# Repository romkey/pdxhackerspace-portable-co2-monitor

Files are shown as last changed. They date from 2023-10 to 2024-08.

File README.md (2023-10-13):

# Build Your Own Portable CO2 Monitor

Build Your Own Portable CO2 Monitor is a [PDX Hackerspace] project.

## Design Goals

- minimize cost
- true CO2 measurement
- choice of displays
- optional Home Assistant integration
- optional battery operation
- version that people who are inexperienced with soldering can build
- more integrated version for people who can assemble surface mount hardware
- open source software and hardware

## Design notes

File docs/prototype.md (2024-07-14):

# Prototype

I built a quick prototype using STEMMA QT/Qwiic connectors. I didn't have any BME280s handy so I used the BME680, which is basically the same thing with a VOC sensor added to it.

STEMMA QT and Qwiic are Adafruit and Sparkfun's branding for identical connectors that allow you to quickly connect 3.3V I2C boards. I2C is great for sensors and very small monochrome displays but it's not fast enough for larger or more colorful displays that need much more data transferred. I2C devices rarely support speeds faster than 400Kbps. Displays that need more speed generally use SPI or parallel or proprietary interfaces.

## Parts

[Adafruit ESP32-S3 QT PY](https://learn.adafruit.com/adafruit-qt-py-esp32-s3/overview)
[SCD40](https://learn.adafruit.com/adafruit-scd-40-and-scd-41)
[BME680](https://learn.adafruit.com/adafruit-bme680-humidity-temperature-barometic-pressure-voc-gas)
[PMSA003I](https://learn.adafruit.com/pmsa003i)
[OLED display]()

## Software

ESPHome components:
[SCD40](https://esphome.io/components/sensor/scd4x)
[BME680](https://esphome.io/components/sensor/bme680)
[PMSA003I](https://esphome.io/components/sensor/pmsa003i)
[SSD1306 OLED](https://esphome.io/components/display/ssd1306)
[Display pages](https://esphome.io/components/display/#display-pages)
[Graphs](https://esphome.io/components/display/#graph-component)

## TODO

The first prototype serves as a proof-of-concept. There are still several areas that need to be verified:

1. running off a battery
2. wireless charging
3. SPI TFT display
4. e-ink display
5. PMS5003 via serial

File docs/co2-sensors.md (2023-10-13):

# CO2 Sensor List

|Device | Interface | Unit cost | Range | Avg Current | Sample Current | Voltage | datasheet
|---|---|---|-----|---|---|---|---
|SCD30| I2C,UART,  PWM | $62 | 400 - 10,000ppm| | | | [datasheet](https://mm.digikey.com/Volume0/opasdata/d220001/medias/docus/743/CD_DS_SCD30_Datasheet_D1.pdf)
|SCD40 | I2C | $30 | 400 - 2000ppm | | | | [datasheet](https://cdn.sparkfun.com/assets/d/4/9/a/d/Sensirion_CO2_Sensors_SCD4x_Datasheet.pdf) |
|SCD41 | I2C | $37 | 400 - 5000ppm | | | | [datasheet](https://cdn.sparkfun.com/assets/d/4/9/a/d/Sensirion_CO2_Sensors_SCD4x_Datasheet.pdf) |
|Senseair S8| UART, I2C | $47 | 400 - 2000ppm | 30mA | | 4.5-5.25V| [datasheet](https://rmtplusstoragesenseair.blob.core.windows.net/docs/publicerat/PSP107.pdf)
|Senseair Sunrise | UART, I2C | $55 | 400 - 5000ppm | 34 µA | 90mA | 3.05-5.5 V | [datasheet](https://rmtplusstoragesenseair.blob.core.windows.net/docs/Dev/publicerat/PSH12460.pdf)
|MH-Z14A | UART | 
|MH-Z19B | UART |
|MQ135| analog | $6 |10～1000ppm | 40mA | 40mA | 5V| [datasheet](https://www.olimex.com/Products/Components/Sensors/Gas/SNS-MQ135/resources/SNS-MQ135.pdf)

* CCS811 and ENS160 are I2C "eCO2" sensors which estimate CO2, not a true CO2 sensors

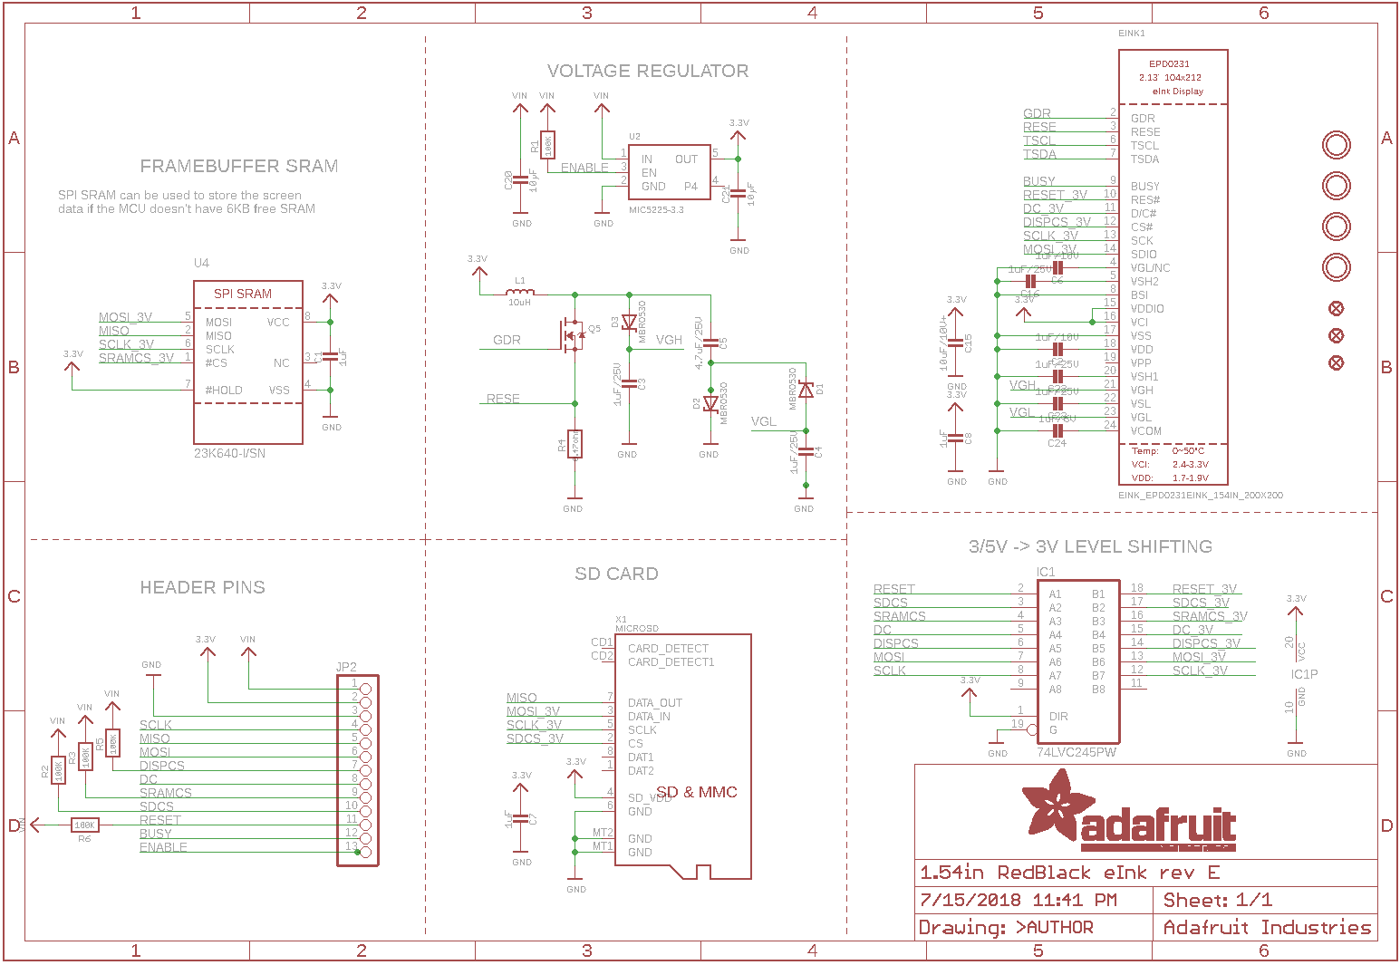
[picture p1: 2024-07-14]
datasheets/adafruit_products_schem.png

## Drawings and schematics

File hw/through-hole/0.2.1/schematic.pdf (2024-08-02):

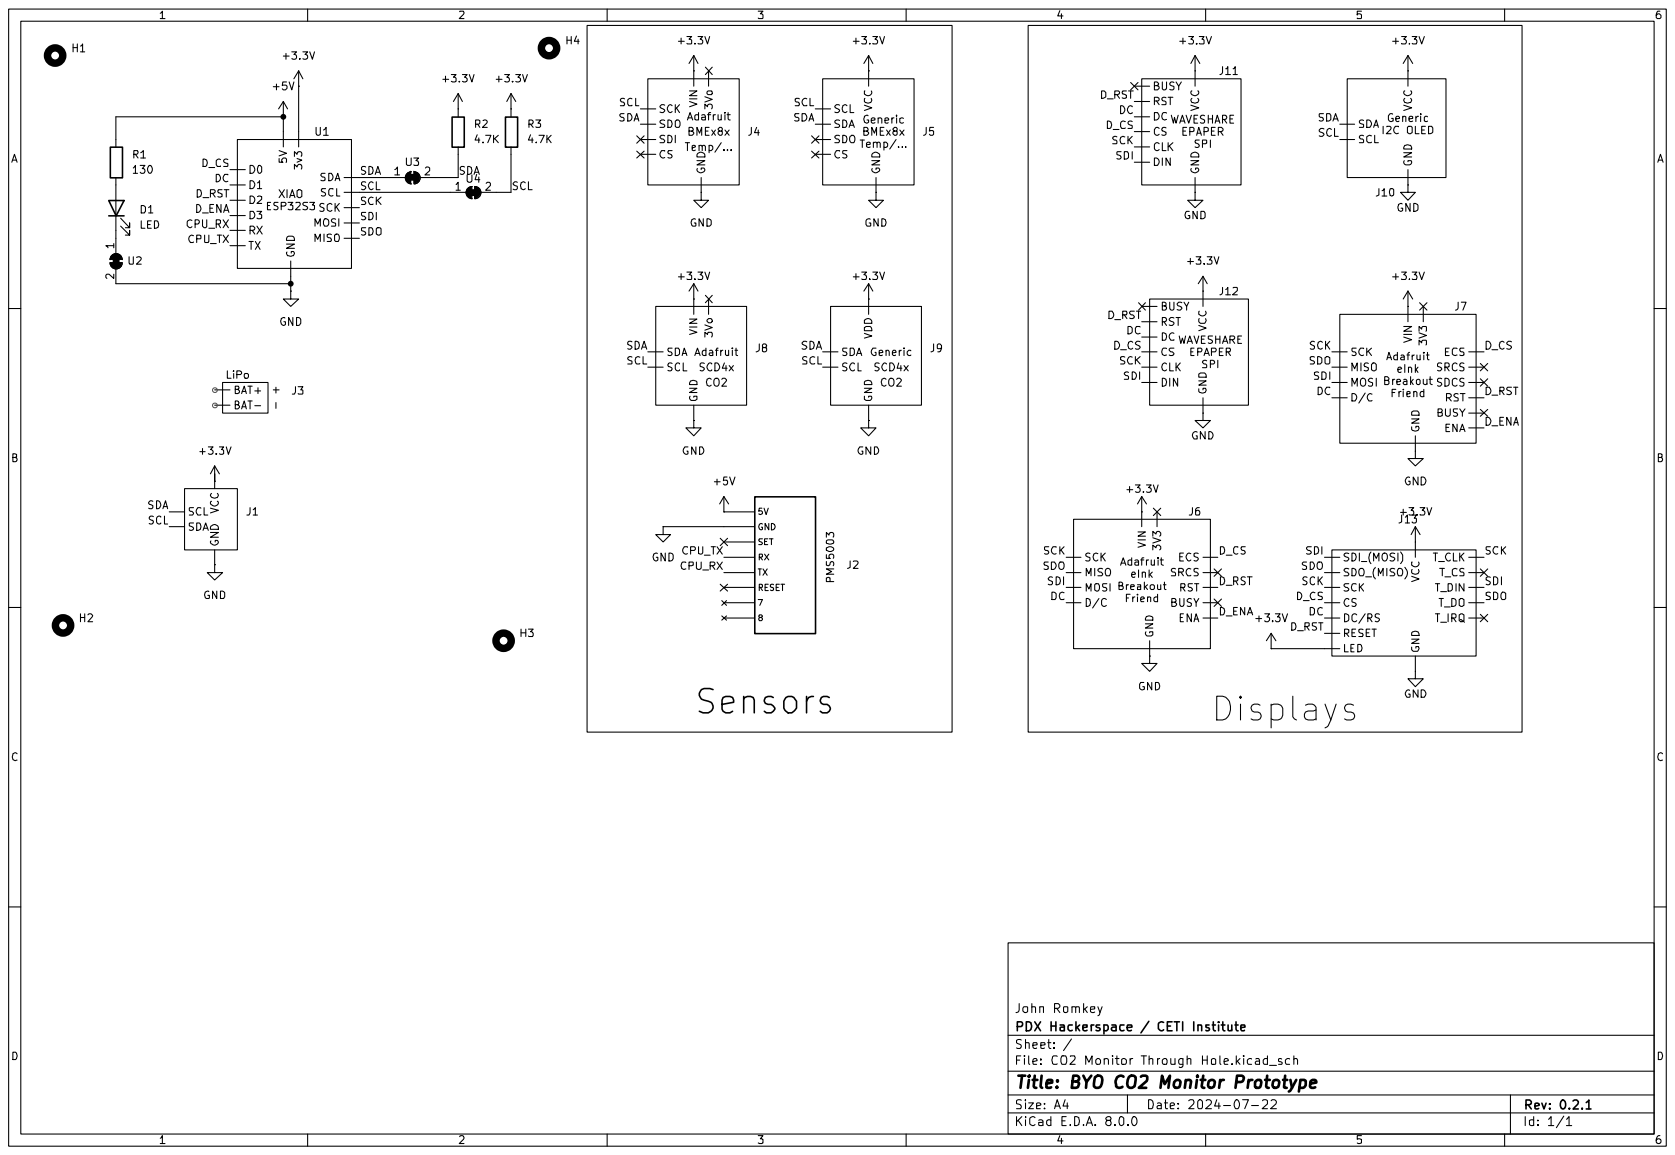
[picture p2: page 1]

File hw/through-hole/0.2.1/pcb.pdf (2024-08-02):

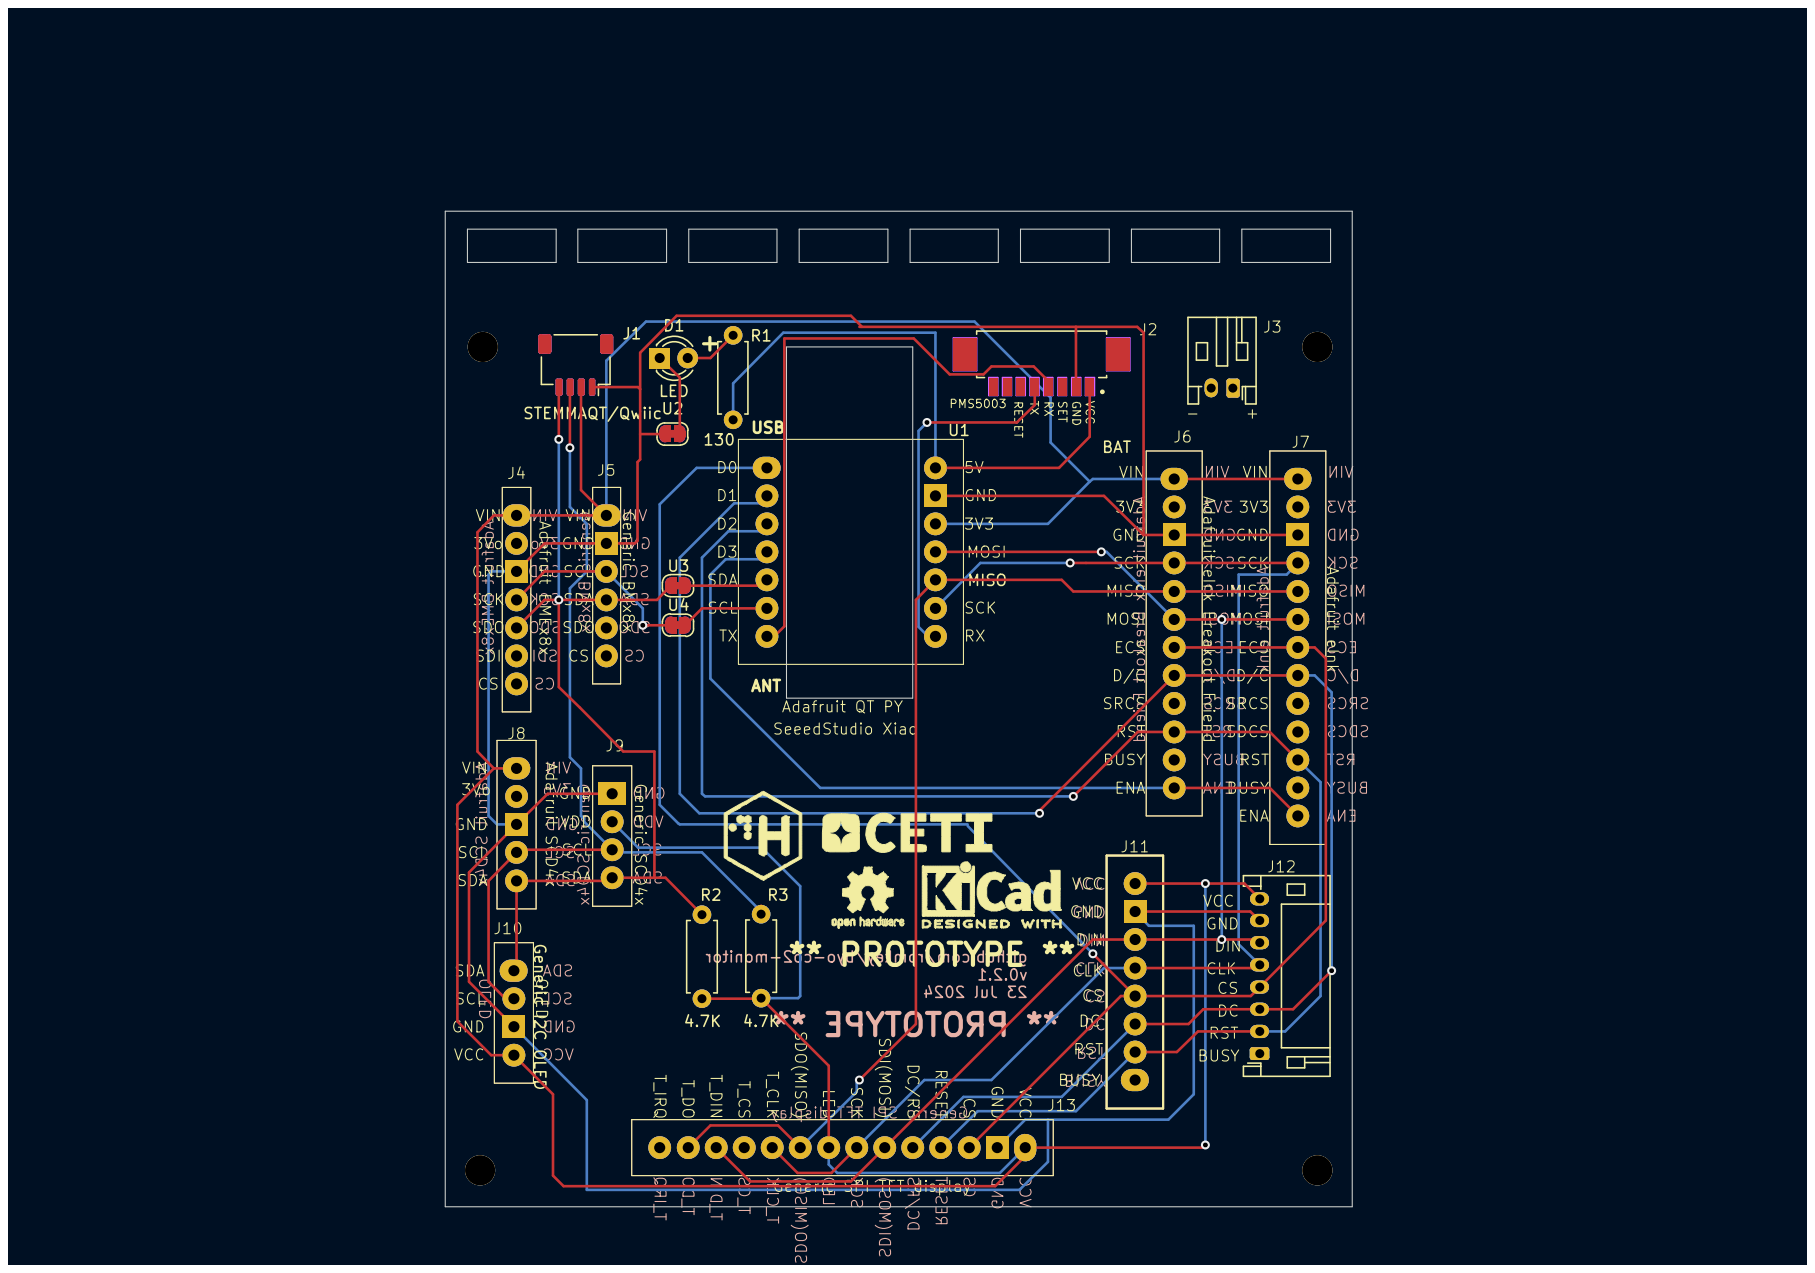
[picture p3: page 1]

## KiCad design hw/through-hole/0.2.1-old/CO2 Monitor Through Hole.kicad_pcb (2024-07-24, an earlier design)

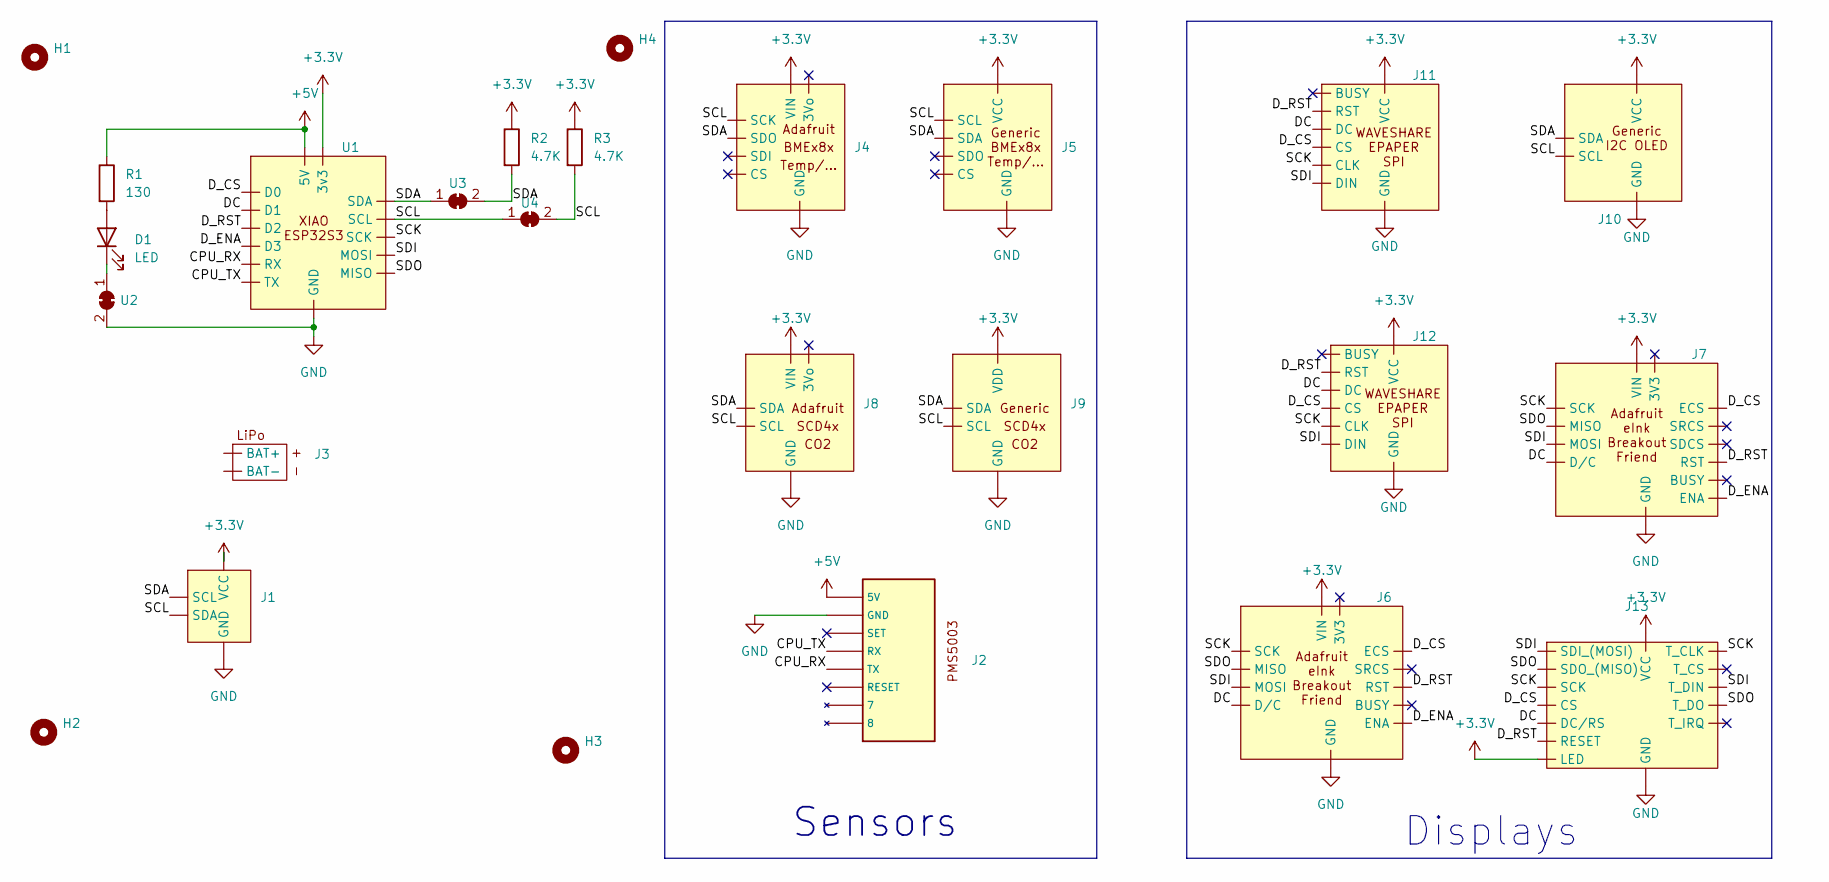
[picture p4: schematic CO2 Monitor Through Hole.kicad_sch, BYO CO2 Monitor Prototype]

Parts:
D1: LED; LED_D3.0mm
H1, H2, H3, H4: MountingHole; MountingHole_2.7mm_M2.5
J1: JST_SH_SM04B-SRSS-TB_1x04-1MP_P1.00mm_Horizontal
J2: PMS5003 Connector
J3: LiPo Connector
J4: Adafruit BMx8x Breakout
J5: Generic BMx8x Breakout
J6: Adafruit eInk Breakout Friend
J7: Adafruit eInk Breakout (GENERIC)
J8: Adafruit SCD4x Breakout
J9: Generic SCD4x Breakout
J10: Generic I2C OLED
J11: Wavshare ePaper SPI
J12: Waveshare ePaper SPI JST
J13: SPI_TFT_TOUCH
R1: 130; R_Axial_DIN0207_L6.3mm_D2.5mm_P7.62mm_Horizontal
R2, R3: 4.7K; R_Axial_DIN0207_L6.3mm_D2.5mm_P7.62mm_Horizontal
U1: Xiao ESP32S3
U2, U3, U4: SolderJumper-2_P1.3mm_Bridged_RoundedPad1.0x1.5mm

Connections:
+3.3V: J1.2 (VCC), J4.1 (VIN), J5.1 (VCC), J6.1 (VIN), J7.1 (VIN), J8.1 (VIN), J9.2 (VDD), J10.4 (VCC), J11.8 (VCC), J12.8 (VCC), J13.1 (VCC), J13.8 (LED), R2.1, R3.1, U1.12 (3v3)
+5V: J2.1 (5V), R1.1, U1.14 (5V)
/CPU_RX: J2.5 (TX), U1.8 (RX)
/CPU_TX: J2.4 (RX), U1.7 (TX)
/DC: J6.8 (D/C), J7.8 (D/C), J11.3 (DC), J12.3 (DC), J13.5 (DC/RS), U1.2 (D1)
/D_CS: J6.7 (ECS), J7.7 (ECS), J11.4 (CS), J12.4 (CS), J13.3 (CS), U1.1 (D0)
/D_ENA: J6.12 (ENA), J7.13 (ENA), U1.4 (D3)
/D_RST: J6.10 (RST), J7.11 (RST), J11.2 (RST), J12.2 (RST), J13.4 (RESET), U1.3 (D2)
/SCK: J6.4 (SCK), J7.4 (SCK), J11.5 (CLK), J12.5 (CLK), J13.7 (SCK), J13.10 (T_CLK), U1.9 (SCK)
/SCL: J1.3 (SDA), J4.4 (SCK), J5.3 (SCL), J8.4 (SCL), J9.3 (SCL), J10.2 (SCL), R3.2, U1.6 (SCL), U4.1 (A), U4.2 (B)
/SDA: J1.4 (SCL), J4.5 (SDO), J5.4 (SDA), J8.5 (SDA), J9.4 (SDA), J10.1 (SDA), R2.2, U1.5 (SDA), U3.1 (A), U3.2 (B)
/SDI: J6.6 (MOSI), J7.6 (MOSI), J11.6 (DIN), J12.6 (DIN), J13.6 (SDI_(MOSI)), J13.12 (T_DIN), U1.11 (MOSI)
/SDO: J6.5 (MISO), J7.5 (MISO), J13.9 (SDO_(MISO)), J13.13 (T_DO), U1.10 (MISO)
GND: J1.1 (GND), J2.2 (GND), J4.3 (GND), J5.2 (GND), J6.3 (GND), J7.3 (GND), J8.3 (GND), J9.1 (GND), J10.3 (GND), J11.7 (GND), J12.7 (GND), J13.2 (GND), U1.13 (GND), U2.2 (B)
unnamed: D1.2 (A), R1.2
unnamed: D1.1 (K), U2.1 (A)

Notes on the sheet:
Sensors
Displays

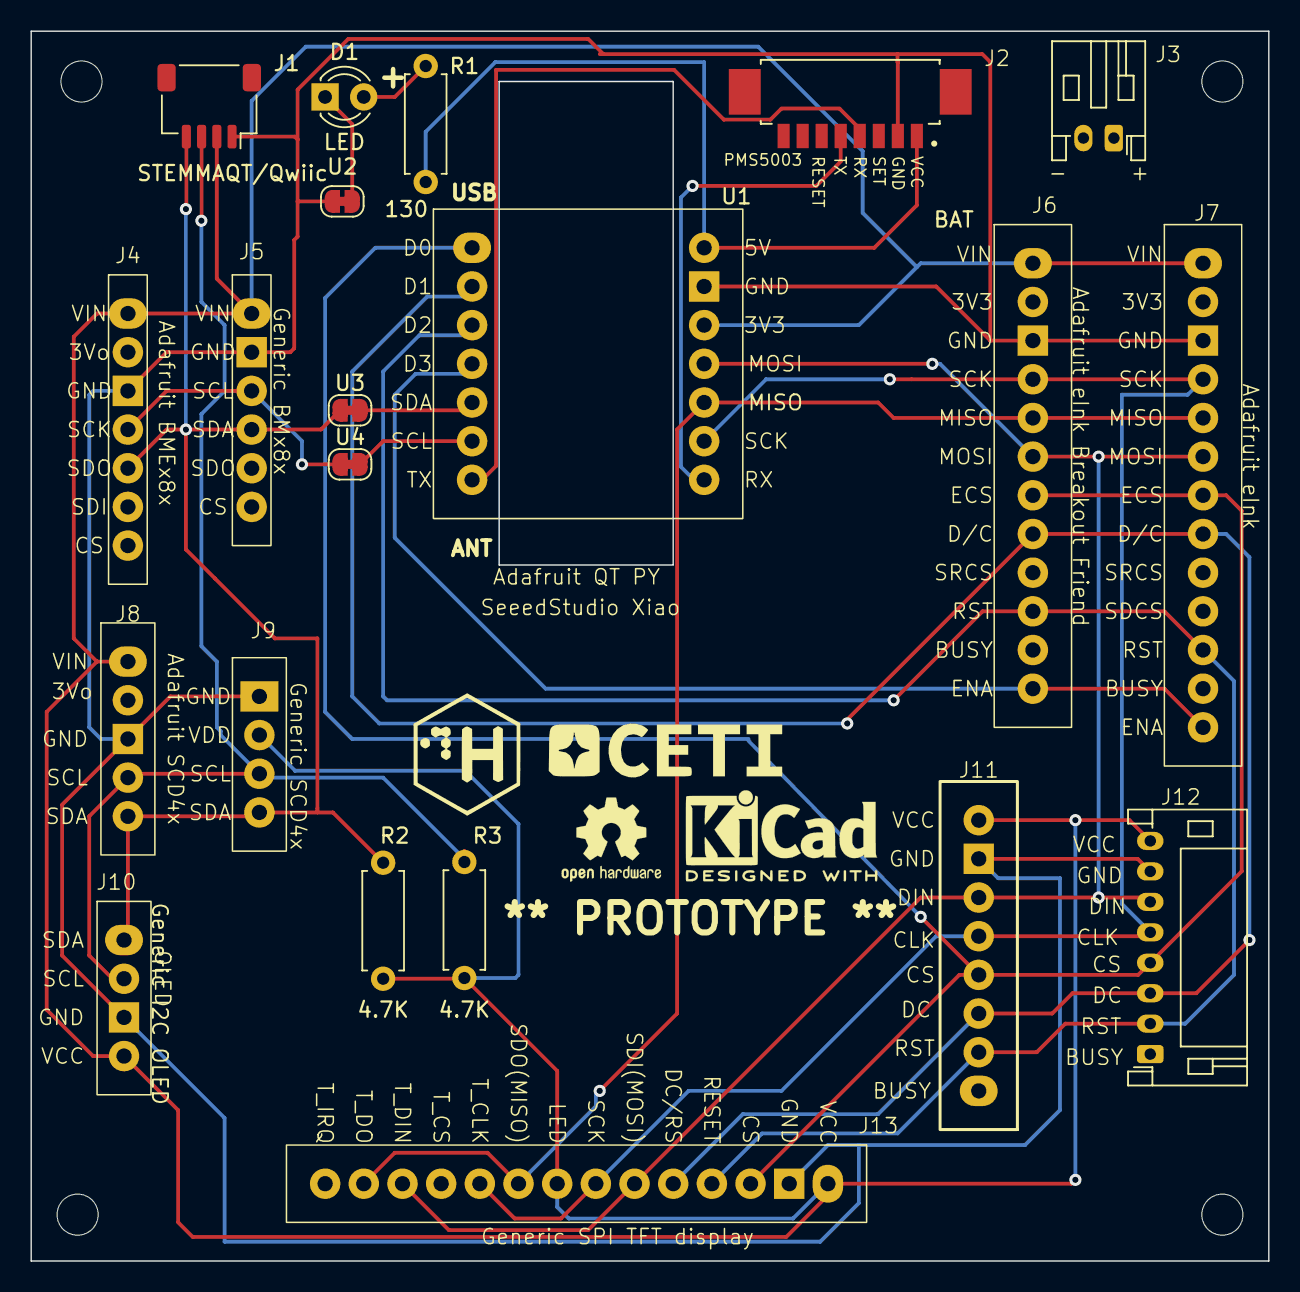
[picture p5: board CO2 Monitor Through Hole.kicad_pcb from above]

Board: 2 copper layers, 81.3 x 80.8 mm, 25 parts (0 on the bottom side), 16 nets.

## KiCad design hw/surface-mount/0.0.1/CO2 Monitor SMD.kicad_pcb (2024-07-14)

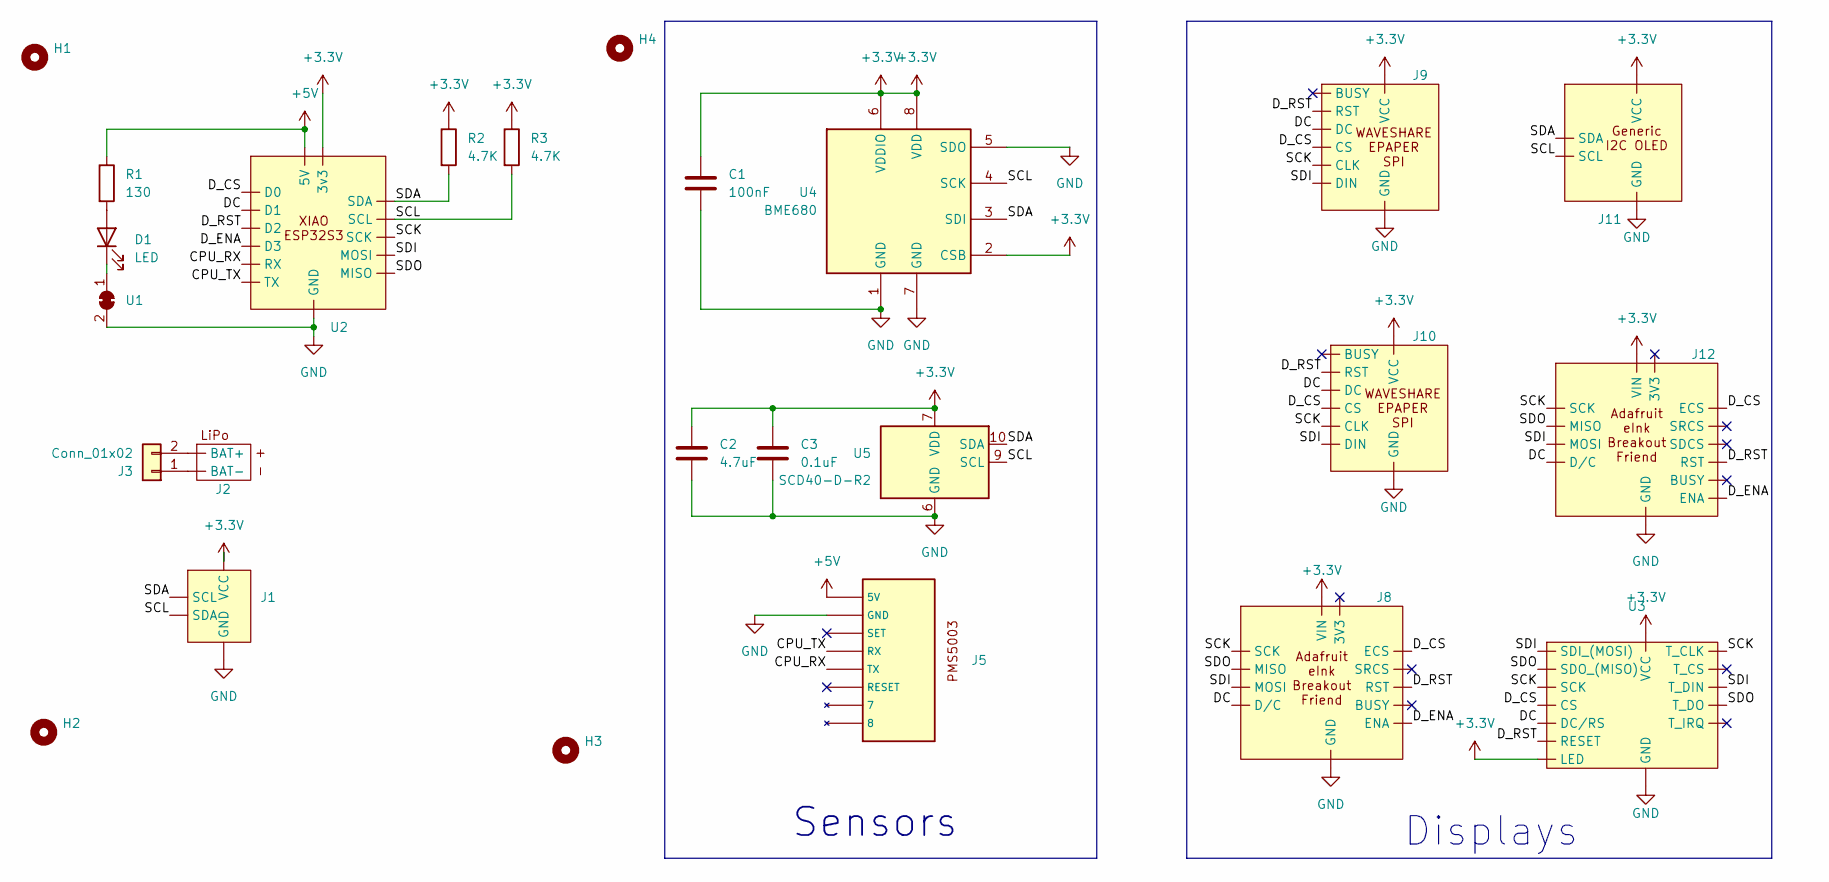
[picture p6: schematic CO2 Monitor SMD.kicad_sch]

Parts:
C1: 100nF; C_1206_3216Metric_Pad1.33x1.80mm_HandSolder
C2: 4.7uF; C_1206_3216Metric_Pad1.33x1.80mm_HandSolder
C3: 0.1uF; C_1206_3216Metric_Pad1.33x1.80mm_HandSolder
D1: LED; LED_1206_3216Metric_Pad1.42x1.75mm_HandSolder
H1, H2, H3, H4: MountingHole; MountingHole_2.7mm_M2.5
J1: JST_SH_SM04B-SRSS-TB_1x04-1MP_P1.00mm_Horizontal
J2: LiPo Connector
J3: Conn_01x02; LiPo Pads
J5: PMS5003 Connector
J8: Adafruit eInk Breakout Friend
J9: Wavshare ePaper SPI
J10: Waveshare ePaper SPI JST
J11: Generic I2C OLED
J12: Adafruit eInk Breakout (GENERIC)
R1: 130; R_1206_3216Metric_Pad1.30x1.75mm_HandSolder
R2, R3: 4.7K; R_1206_3216Metric_Pad1.30x1.75mm_HandSolder
U1: SolderJumper-2_P1.3mm_Bridged_RoundedPad1.0x1.5mm
U2: Xiao ESP32S3
U3: SPI_TFT_TOUCH
U4: BME680; Bosch_LGA-8_3x3mm_P0.8mm_ClockwisePinNumbering
U5: SCD40-D-R2; Sensirion_SCD4x-1EP_10.1x10.1mm_P1.25mm_EP4.8x4.8mm

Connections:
+3.3V: C1.1, C2.1, C3.1, J1.2 (VCC), J8.1 (VIN), J9.8 (VCC), J10.8 (VCC), J11.4 (VCC), J12.1 (VIN), R2.1, R3.1, U2.12 (3v3), U3.1 (VCC), U3.8 (LED), U4.2 (CSB), U4.6 (VDDIO), U4.8 (VDD), U5.7 (VDD), U5.19 (VDD)
+5V: J5.1 (5V), R1.1, U2.14 (5V)
/CPU_RX: J5.5 (TX), U2.8 (RX)
/CPU_TX: J5.4 (RX), U2.7 (TX)
/DC: J8.8 (D/C), J9.3 (DC), J10.3 (DC), J12.8 (D/C), U2.2 (D1), U3.5 (DC/RS)
/D_CS: J8.7 (ECS), J9.4 (CS), J10.4 (CS), J12.7 (ECS), U2.1 (D0), U3.3 (CS)
/D_ENA: J8.12 (ENA), J12.13 (ENA), U2.4 (D3)
/D_RST: J8.10 (RST), J9.2 (RST), J10.2 (RST), J12.11 (RST), U2.3 (D2), U3.4 (RESET)
/SCK: J8.4 (SCK), J9.5 (CLK), J10.5 (CLK), J12.4 (SCK), U2.9 (SCK), U3.7 (SCK), U3.10 (T_CLK)
/SCL: J1.3 (SDA), J11.2 (SCL), R3.2, U2.6 (SCL), U4.4 (SCK), U5.9 (SCL)
/SDA: J1.4 (SCL), J11.1 (SDA), R2.2, U2.5 (SDA), U4.3 (SDI), U5.10 (SDA)
/SDI: J8.6 (MOSI), J9.6 (DIN), J10.6 (DIN), J12.6 (MOSI), U2.11 (MOSI), U3.6 (SDI_(MOSI)), U3.12 (T_DIN)
/SDO: J8.5 (MISO), J12.5 (MISO), U2.10 (MISO), U3.9 (SDO_(MISO)), U3.13 (T_DO)
GND: C1.2, C2.2, C3.2, J1.1 (GND), J5.2 (GND), J8.3 (GND), J9.7 (GND), J10.7 (GND), J11.3 (GND), J12.3 (GND), U1.2 (B), U2.13 (GND), U3.2 (GND), U4.1 (GND), U4.5 (SDO), U4.7 (GND), U5.6 (GND), U5.20 (GND), U5.21 (GND)
unnamed: D1.2 (A), R1.2
unnamed: D1.1 (K), U1.1 (A)
unnamed: J2.2 (BAT+), J3.2
unnamed: J2.1 (BAT-), J3.1

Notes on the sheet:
Displays
Sensors

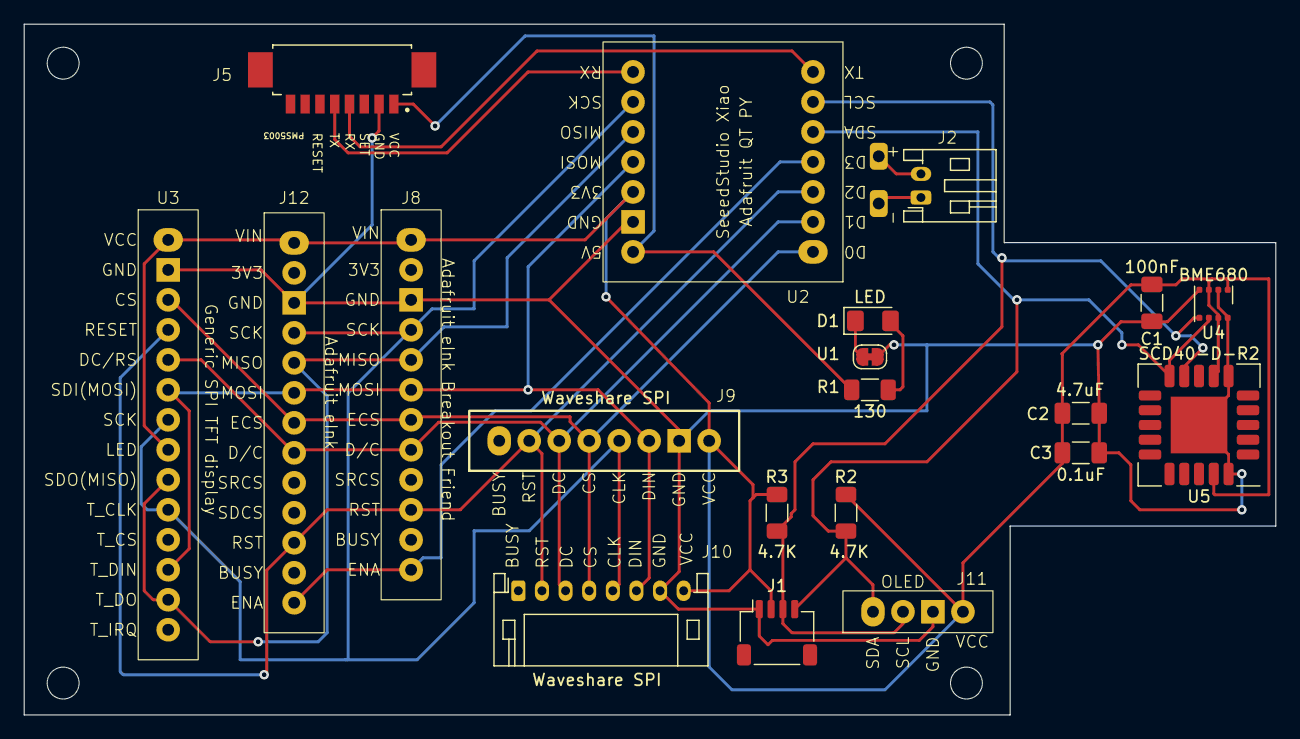
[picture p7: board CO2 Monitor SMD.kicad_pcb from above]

Board: 2 copper layers, 106.0 x 58.5 mm, 25 parts (0 on the bottom side), 18 nets.

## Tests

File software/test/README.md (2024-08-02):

# CircuitPython

There is currently no build of CircuitPython for the Xiao ESP32-S3. Use the [ESP32-S3-DevKitC-1-N8 build](https://circuitpython.org/board/espressif_esp32s3_devkitc_1_n8/) instead and ignore its built-in pin definitions.

# E-ink Displays

## Waveshare 1.54in e-Paper Module Rev 2.1

200x200

[link](https://www.waveshare.com/1.54inch-e-Paper-Module.htm)
```

```

## Waveshare 2.13in e-Paper HAT Rev 2.1

250x122

[link](https://www.waveshare.com/2.13inch-e-Paper-HAT.htm)

```Python
SSD1680
width=display = adafruit_ssd1680.SSD1680(
    display_bus,
    width=296,
    height=128,
    highlight_color=0xFF0000,
    rotation=270,
)
```

## Waveshare 2.9in e-Paper Module

296x128

[link](https://www.waveshare.com/product/displays/e-paper/epaper-2/2.9inch-e-paper-module.htm?___SID=U)
```

```

## Waveshare 4.2in e-Paper Module

400x300 B&W

[link](https://www.waveshare.com/4.2inch-e-Paper-Module.htm)
```

```

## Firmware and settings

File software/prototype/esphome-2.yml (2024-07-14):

esphome:
  name: multimultigas
  friendly_name: MultiMultiGas
#  includes:
#    - multi_multigas.h
  libraries:
    - Wire
    - https://github.com/DFRobot/DFRobot_MultiGasSensor
    - https://github.com/romkey/multi-multigas

esp32:
  board: adafruit_qtpy_esp32s3_nopsram
  framework:
    type: arduino

# Enable logging
logger:

# Enable Home Assistant API
api:
  encryption:
    key: 

ota:
  password: 

wifi:
  ssid: !secret wifi_ssid
  password: !secret wifi_password
  manual_ip: 
    static_ip: 10.0.1.125
    subnet: 255.255.255.0
    dns1: 10.0.1.1
    gateway: 10.0.1.1

  # Enable fallback hotspot (captive portal) in case wifi connection fails
  ap:
    ssid: "Multimultigas Fallback Hotspot"
    password: 

captive_portal:

external_components:
  - source:
      type: local
      path: "/config/my_components"
    components: [ "multi_gas" ]


#globals:
#  - id: gas_sensor
#    type: MultiMultiGas

i2c:
  sda: 41
  scl: 40
  frequency: 100khz
  scan: true

debug:
  update_interval: 5s

font:
  - file: 'fonts/B612-Regular.ttf'
    id: font_20pt
    size: 20

graph:
  - id: co2_graph
    height: 64
    width: 128
    duration: 15min
    traces:
      - sensor: co2
        continuous: true
  - id: temp_graph
    height: 64
    width: 128
    sensor: bme680_temp
    duration: 15min

  - id: humidity_graph
    sensor: bme680_hum
    height: 64
    width: 128
    duration: 15min

  - id: hcho_graph
    sensor: formaldehyde
    height: 64
    width: 128
    duration: 15min

  - id: no2_graph
    sensor: no2
    height: 64
    width: 128
    duration: 15min

  - id: nh3_graph
    sensor: nh3
    height: 64
    width: 128
    duration: 15min

  - id: o3_graph
    sensor: o3
    height: 64
    width: 128
    duration: 15min

  - id: hcl_graph
    sensor: hcl
    height: 64
    width: 128
    duration: 15min

  - id: h2s_graph
    sensor: h2s
    height: 64
    width: 128
    duration: 15min

  - id: co_graph
    sensor: co
    height: 64
    width: 128
    duration: 15min

  - id: pm_2_5_graph
    sensor: pm_2_5
    height: 64
    width: 128
    duration: 15min


time:
  - platform: homeassistant
    id: homeassistant_time
    timezone: America/Los_Angeles

interval:
  - interval: 5s
    then:
      - display.page.show_next: my_display
      - component.update: my_display

display:
  - platform: ssd1327_i2c
    model: "SSD1327 128x128"
    id: my_display
#    reset_pin: D0
    address: 0x3D
    auto_clear_enabled: True    
    pages:
      - id: page_time
        lambda: |-
          auto time = id(homeassistant_time).now();
          if(time.is_valid()) {
            it.printf(20, 50, id(font_20pt), "%02d:%02d:%02d", time.hour, time.minute, time.second);
            }
      - id: page_temperature
        lambda: |-
          if(isnan(id(bme680_temp).state)) {
            id(my_display).show_next_page();
            return;
            }

          it.printf(10, 10, id(font_20pt), "Temp %0.1f°C", id(bme680_temp).state);
          it.graph(0, 60, id(temp_graph));


      - id: page_humidity
        lambda: |-
          if(isnan(id(bme680_hum).state)) {
            id(my_display).show_next_page();
            return;
            }

          it.printf(10, 10, id(font_20pt), "Hum %0.0f%%", id(bme680_hum).state);
          it.graph(0, 60, id(humidity_graph));


      - id: page_co2
        lambda: |-
          if(isnan(id(co2).state)) {
            id(my_display).show_next_page();
            return;
            }

          it.printf(10, 10, id(font_20pt), "CO2 %0.0f ppm", id(co2).state);
          it.graph(0, 60, id(co2_graph));


      - id: page_co
        lambda: |-
          if(isnan(id(co).state)) {
            id(my_display).show_next_page();
            return;
            }

          it.printf(10, 10, id(font_20pt), "CO %0.0f ppm", id(co).state);
          it.graph(0, 60, id(co_graph));


      - id: page_h2s
        lambda: |-
          if(isnan(id(h2s).state)) {
            id(my_display).show_next_page();
            return;
            }

          it.printf(10, 10, id(font_20pt), "H2S %0.0f ppm", id(h2s).state);
          it.graph(0, 60, id(h2s_graph));


      - id: page_hcl
        lambda: |-
          if(isnan(id(hcl).state)) {
            id(my_display).show_next_page();
            return;
            }

          it.printf(10, 10, id(font_20pt), "HCL %0.0f ppm", id(hcl).state);
          it.graph(0, 60, id(hcl_graph));


      - id: page_o3
        lambda: |-
          if(isnan(id(o3).state)) {
            id(my_display).show_next_page();
            return;
            }

          it.printf(10, 10, id(font_20pt), "O3 %0.0f ppm", id(o3).state);
          it.graph(0, 60, id(o3_graph));


      - id: page_nh3
        lambda: |-
          if(isnan(id(nh3).state)) {
            id(my_display).show_next_page();
            return;
            }

          it.printf(10, 10, id(font_20pt), "NH3 %0.0f ppm", id(nh3).state);
          it.graph(0, 60, id(nh3_graph));
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

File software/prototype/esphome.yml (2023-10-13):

esphome:
  name: portable-co2-sensor
  friendly_name: Portable CO2 Sensor

esp32:
  board: adafruit_qtpy_esp32s3_nopsram
  framework:
    type: arduino

# Enable logging
logger:

# Enable Home Assistant API
api:
  encryption:
    key: "oh-no-you-don't"

ota:
  password: "not this either"

wifi:
  ssid: !secret wifi_ssid
  password: !secret wifi_password

  # Enable fallback hotspot (captive portal) in case wifi connection fails
  ap:
    ssid: "Portable-Co2-Sensor"
    password: "nor this"

captive_portal:

font:
  - file: 'fonts/B612-Regular.ttf'
    id: font1
    size: 12
  - file: 'fonts/B612-Regular.ttf'
    id: font_larger
    size: 20

spi:
  clk_pin: GPIO36
  mosi_pin: GPIO35
  miso_pin: GPIO37

i2c:
  sda: GPIO41
  scl: GPIO40

# this isn't working
display:
  - platform: waveshare_epaper
    cs_pin: GPIO18
    dc_pin: GPIO17
#    busy_pin: D4
#    reset_pin: D5
    model: 2.90in
    full_update_every: 30
    lambda: |-
      it.print(0, 0, id(font1), "Hello World!");

# this is
  - platform: ssd1306_i2c
    model: "SSD1306 128x64"
    id: ssd_display
#    reset_pin: D0
    address: 0x3D
    pages:
      - id: page1
        lambda: |-
         it.print(0, 0, id(font1), "CO2");
         it.printf(40, 0, id(font1), "%4.0f", id(co2).state);
         it.print(0, 14, id(font1), "Temp");
         it.printf(40, 14, id(font1), "%.1f", id(bme_temperature).state);
         it.print(0, 28, id(font1), "Humd");
         it.printf(40, 28, id(font1), "%.1f%%", id(bme_humidity).state);
         it.print(0, 42, id(font1), "PM");
         it.printf(40, 42, id(font1), "%f.0/%f.0/%f.0", id(pm_1_0).state, id(pm_2_5).state, id(pm_10_0).state);
      - id: page2
        lambda: |-
          it.print(0, 0, id(font_larger), "CO2");
          it.graph(0, 21, id(co2_graph));
      - id: page3
        lambda: |-
          it.print(0, 0, id(font_larger), "PM");
          it.graph(0, 21, id(pm_graph));
      - id: page4
        lambda: |-
          it.print(0, 0, id(font_larger), "Temperature");
          it.graph(0, 21, id(temperature_graph));          
      - id: page5
        lambda: |-
          it.print(0, 0, id(font_larger), "Humidity");
          it.graph(0, 21, id(humidity_graph));
      - id: page6
        lambda: |-
          it.print(0, 0, id(font_larger), "Pressure");
          it.graph(0, 21, id(pressure_graph));

# For example cycle through pages on a timer
interval:
  - interval: 5s
    then:
      - display.page.show_next: ssd_display
      - component.update: ssd_display

graph:
  - id: co2_graph
    sensor: co2
    duration: 1h
    width: 128
    height: 43
  - id: temperature_graph
    sensor: bme_temperature
    duration: 1h
    width: 128
    height: 43
  - id: humidity_graph
    sensor: bme_humidity
    duration: 1h
    width: 128
    height: 43
  - id: pressure_graph
    sensor: bme_pressure
    duration: 1h
    width: 128
    height: 43
  - id: pm_graph
    duration: 1h
    width: 128
    height: 43
    traces:
      - sensor: pm_1_0
        line_type: DASHED
        line_thickness: 1
      - sensor: pm_2_5
        line_type: SOLID
        line_thickness: 1
      - sensor: pm_10_0
        line_type: DOTTED
        line_thickness: 1

sensor:
  - platform: pmsa003i
    pm_1_0:
      name: "PM1.0"
      id: pm_1_0
    pm_2_5:
      name: "PM2.5"
      id: pm_2_5
    pm_10_0:
      name: "PM10.0"
      id: pm_10_0
    pmc_0_3:
      name: "PMC >0.3µm"
    pmc_0_5:
      name: "PMC >0.5µm"
    pmc_1_0:
      name: "PMC >1µm"
    pmc_2_5:
      name: "PMC >2.5µm"
    pmc_5_0:
      name: "PMC >5µm"
    pmc_10_0:
      name: "PMC >10µm"

  - platform: scd4x
    id: co2_sensor
    co2:
      name: "CO2"
      id: co2
    temperature:
      name: "SCD Temperature"
    humidity:
      name: "SCD Humidity"

  - platform: bme680
    id: temp_sensor
    temperature:
      name: "BME680 Temperature"
      oversampling: 16x
      id: bme_temperature
    pressure:
      name: "BME680 Pressure"
      id: bme_pressure
    humidity:
      name: "BME680 Humidity"
      id: bme_humidity
    gas_resistance:
      name: "BME680 Gas Resistance"
    address: 0x77
    update_interval: 60s

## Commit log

2023-10-13 added prototype esphome.yml
2023-10-13 fixed graph display in prototype
    [esphome.yml]
2024-07-14 added latest KiCAD projects, datasheets, updated esphome code
    [CO2 Monitor SMD.kicad_pcb, CO2 Monitor SMD.kicad_sch, CO2 Monitor.kicad_pcb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]
2024-07-23 test version of 0.2.0 prototype hardware
    [CO2 Monitor Through Hole.kicad_pcb, CO2 Monitor Through Hole.kicad_sch]
2024-07-23 minor silkscreen updates
    [CO2 Monitor Through Hole.kicad_pcb]
2024-07-24 version 0.2.1 of the hardware
    [CO2 Monitor Through Hole.kicad_pcb, CO2 Monitor Through Hole.kicad_sch]
2024-08-02 updated 0.2.1 hardware
    added software tests
    [CO2 Monitor Through Hole.kicad_pcb, CO2 Monitor Through Hole.kicad_sch]
